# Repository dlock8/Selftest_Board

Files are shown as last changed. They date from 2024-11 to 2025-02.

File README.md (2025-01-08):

# FIRST STATION TEST Selftest Box Assembly 500-1010-021

## Project Overview
This project involves the assembly of a custom **Selftest Circuit Board (PCB)** designed to be part of the **First TestStation** project ([FTS](https://dlock8.github.io/FTS_Website/)).<br>
The primary goal of the selftest board is to provide the necessary electronics and multiple connections to validate the [Interconnect IO Box](https://github.com/dlock8/InterconnectIO_Box).<br>

## Note
Due to minor additions, the Selftest Board Assembly has been updated to become the Selftest Box Assembly. The documentation for these updates has been included in the same repository.

## Documentation

- [Bill of Materials (BOM)](selftest_bd/pdf/BOM_Selftest_Box_510-1010.pdf) – List of components required for assembly.

<br>
<br>

# FIRST STATION TEST Selftest Board Assembly 600-1010-021

This section contains the materials and instructions required to assemble the Selftest Board.

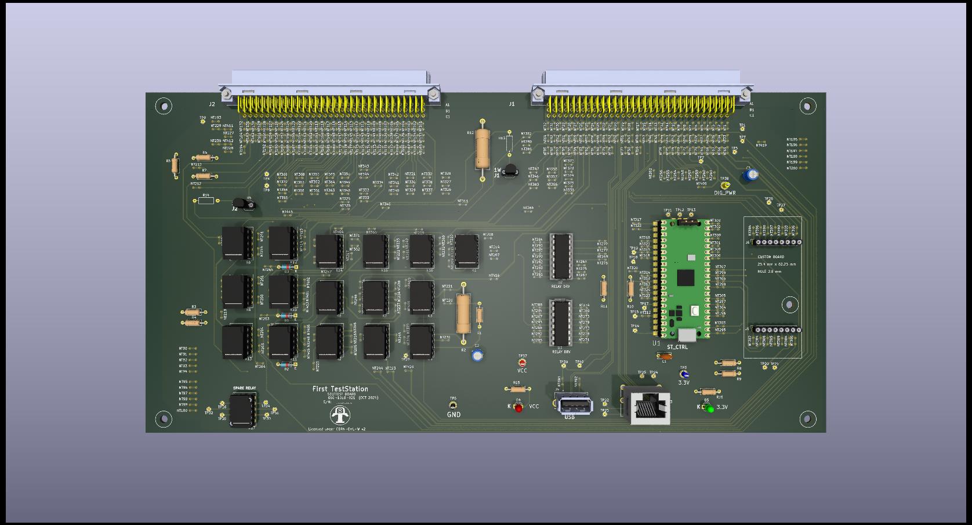
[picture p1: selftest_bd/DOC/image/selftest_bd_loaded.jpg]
Board
 

### Design Tools
- [KiCad 7](https://www.kicad.org/download/) - Free software application used to design the PCB.
- [LibreOffice](https://www.libreoffice.org/download/download-libreoffice/) - Free Software application used to create assembly instructions and the Bill of Materials (BOM).
- [PicPick](https://picpick.app/en/) - Free application to capture and document image.

---
### Features
- **Easy Hand Assembly**: Designed with only through-hole components, making it easy to assemble by hand.
- **Socketed Active Components**: To facilitate easy replacement without unsoldering, most active components are mounted on sockets.
- **Cost-Effective Controller**: The low-cost and powerful **Raspberry Pi Pico Microcontroller** is used to interface with the user and control internal electronics.

## Assembly Instructions
   Follow the document [Assembly_Instructions](selftest_bd/pdf/Selftest_Assembly_Instruction_680-1010.pdf) to complete the assembly of the board.

## Design Files
- [Gerber Files](https://github.com/dlock8/Selftest_Board/tree/main/selftest_bd/gerber_to_order) – Gerber files for PCB fabrication (JLCPCB is the one used by the project).
- [Assembly Schematic](selftest_bd/pdf/Selftest_Assembly_Diagram_670-1010.pdf) – Parts and value to help hand assemblies of components.
- [Electrical Schematic](selftest_bd/pdf/Selftest_Schematic_640-1010.pdf) – Review the full electrical schematic diagram for reference.
- [Bill of Materials (BOM)](selftest_bd/pdf/BOM_Selftest_Board_610-1010.pdf) – List of components required for assembly.

---

## License

This project is licensed under the terms of the [CERN Open Hardware Licence Version 2 - Weakly Reciprocal (CERN-OHL-W 2.0)](https://ohwr.org/cern_ohl_w_v2.txt).

See the [LICENSE](./LICENSE) file in this repository for more details.

---

## History
- **Version 1.0**: The initial version of the PCB (600-1010-010) was assembled and tested. However, the main connectors J1 and J2 were reversed, making the board unusable.
- **Version 2.0**:This version includes corrections to the connector errors. The board was assembled and tested, but errors were found in the wiring of the USB and RJ45 connectors.
- **Version 2.1**: This version addresses all errors identified in Version 2.0. As of now, Version 2.1 has not yet been assembled or tested.
---

## Contact
For any issues or further questions, feel free to contact me at [daniellockhead@gmail.com] or open an issue on GitHub.

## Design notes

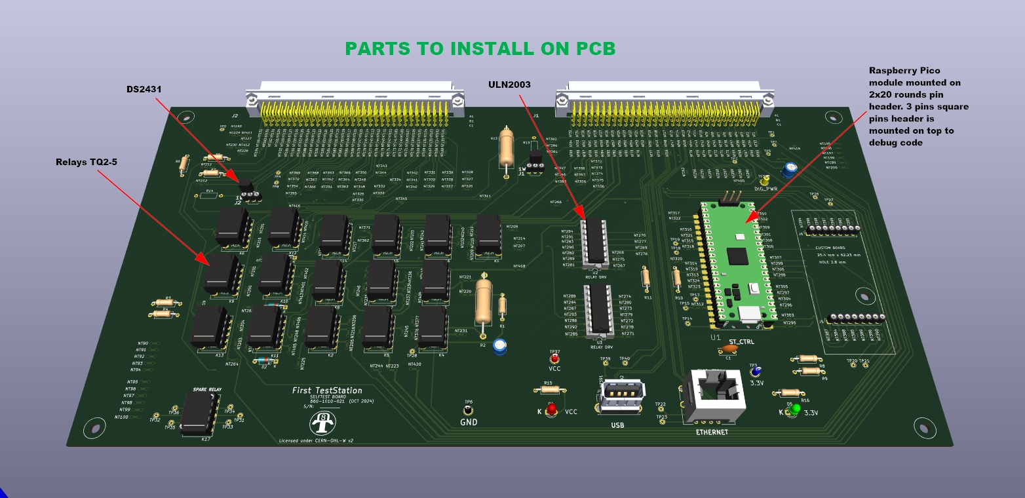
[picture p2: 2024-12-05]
selftest_bd/DOC/image/selftest_bd_loaded2.jpg

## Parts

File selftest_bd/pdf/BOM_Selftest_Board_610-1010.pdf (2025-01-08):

# BOM Selest Board

610-1010-021

Component for this board has been selected to be not expensive and available over the world. The quanty specified on the BOM are the required quanty and not the quanty received because most of the components sales by AliExpress are coming in a lot of 5 or more.

ITEM | Ref | Qty | Value | Component number | Component Link | Footprint
1 | C1, | 1 | 0.1uF | 104(0.1uF) | hps://www.aliexpress.com/item/1005002290441861.html?spm=a2g0o.cart.0.0.47a938dapeqfLF&mp=1 | Capacitor_THT:C_Disc_D6.0mm_W2.5mm_P5.00mm
2 | C2, C3, | 2 | 10uF | Need 10uF only | hps://www.aliexpress.com/item/1005001831366715.html?spm=a2g0o.order_list.order_list_main.128.18751802TGrCM3 | Capacitor_THT:CP_Radial_D4.0mm_P1.50mm
3 | D1, D2, D3, | 3 | 1N4148 | D0-35 | hps://www.aliexpress.com/item/1005002761024460.html?spm=a2g0o.order_list.order_list_main.134.18751802TGrCM3 | Diode_THT:D_DO-35_SOD27_P7.62mm_Horizontal
4 | D4, D5 | 2 | Red,Green Led 3m 5 color mixing | | hps://www.aliexpress.com/item/32890682652.html?spm=a2g0o.cart.0.0.484b38da3R3jzV&mp=1 | LED_THT:LED_D3.0mm
5 | J1, J2, | 2 | 9001-14961C00A | 396-RA-F | hps://www.aliexpress.com/item/32808173331.html?spm=a2g0o.order_detail.order_detail_item.3.8a9af19cRF49dn | 9001-11961:900114961C00A
6 | J3, | 1 | RJ45 | NO LED 180 Degress | hps://www.aliexpress.com/item/4001249545815.html?spm=a2g0o.order_list.order_list_main.5.21ef18023qhtdr | RJ45:CUI_CRJ028-1H-TH
7 | J4, | 1 | USB-VERTICAL | USB-A1VSB6 | hps://www.aliexpress.com/item/1005003366091753.html?spm=a2g0o.order_detail.order_detail_item.3.16c6f19cv420cM | USB-A:ONSHORE_USB-A1VSB6
8 | J5, J6, | 2 | 8 x 2.54mm | Cut to length | hps://www.aliexpress.com/item/1005005053790061.html?spm=a2g0o.order_list.order_list_main.16.2c1a1802vA8wf5 | Connector_PinSocket_2.54mm:PinSocket_1x08_P2.54mm_Vercal
9 | K1,K2,K3,K4,K5,K6,K7,K8,K9,K10,K11, K12,K13,K14,K15,K16,K17 | 17 | TQ2-5 | TQ2-5V | hps://www.aliexpress.com/item/1005004349797638.html?spm=a2g0o.order_detail.order_detail_item.3.29bdf19cH6EBpl | Relay_THT:Relay_DPDT_FRT5
10 | R1, | 1 | 100 | 1% 1/4W Resistor Kit | hps://www.aliexpress.com/item/1005001818485416.html?spm=a2g0o.cart.0.0.405a38daqyYISw&mp=1 | Resistor_THT:R_Axial_DIN0207_L6.3mm_D2.5mm_P10.16mm_Horizontal
11 | R2,R12, | 2 | 10 | 10R 3W | hps://www.aliexpress.com/item/1005005249422833.html?spm=a2g0o.cart.0.0.6c0b38dax2jDId&mp=1 | Resistor_THT:R_Axial_DIN0617_L17.0mm_D6.0mm_P25.40mm_Horizontal
12 | R3, R4, R10,R11 | 2 | 10K | 1% 1/4W Resistor Kit | hps://www.aliexpress.com/item/1005001818485416.html?spm=a2g0o.cart.0.0.405a38daqyYISw&mp=1 | Resistor_THT:R_Axial_DIN0309_L9.0mm_D3.2mm_P12.70mm_Horizontal
13 | R6, | 1 | 10 | 1% 1/4W Resistor Kit | hps://www.aliexpress.com/item/1005001818485416.html?spm=a2g0o.cart.0.0.405a38daqyYISw&mp=1 | Resistor_THT:R_Axial_DIN0207_L6.3mm_D2.5mm_P10.16mm_Horizontal
14 | R5,R7 | 2 | 4.7 | 1% 1/4W Low value Resistor Kit | hps://www.aliexpress.com/item/4000174550644.html?spm=a2g0o.order_list.order_list_main.47.641f1802HxQ52S | Resistor_THT:R_Axial_DIN0207_L6.3mm_D2.5mm_P10.16mm_Horizontal
15 | R8, R9, R13, R14 | 2 | 4.7K | 1% 1/4W Resistor Kit | hps://www.aliexpress.com/item/1005001818485416.html?spm=a2g0o.cart.0.0.405a38daqyYISw&mp=1 | Resistor_THT:R_Axial_DIN0207_L6.3mm_D2.5mm_P10.16mm_Horizontal
16 | R13, R14 | 2 | Not Installed | 1% 1/4W Resistor Kit | hps://www.aliexpress.com/item/1005001818485416.html?spm=a2g0o.cart.0.0.405a38daqyYISw&mp=1 | Resistor_THT:R_Axial_DIN0207_L6.3mm_D2.5mm_P10.16mm_Horizontal
17 | R15, | 1 | 470 | 1% 1/4W Resistor Kit | hps://www.aliexpress.com/item/1005001818485416.html?spm=a2g0o.cart.0.0.405a38daqyYISw&mp=1 | Resistor_THT:R_Axial_DIN0207_L6.3mm_D2.5mm_P10.16mm_Horizontal
18 | R16, | 1 | 330 | 1% 1/4W Resistor Kit | hps://www.aliexpress.com/item/1005001818485416.html?spm=a2g0o.cart.0.0.405a38daqyYISw&mp=1 | Resistor_THT:R_Axial_DIN0207_L6.3mm_D2.5mm_P10.16mm_Horizontal
19 | U1, | 1 | Rasberry Pico | SC0915 | hps://www.digikey.ca/en/products/detail/raspberry-pi/SC0915/13624793?s=N4IgTCBcDaIMoGEAMBOAjAVhAXQL5A | MCU_RaspberryPi_and_Boards:RPi_Pico_SMD_TH
20 | U1_male_pin | 1 | 20 x 2.54mm | 1x40P male L-11.96mm | hps://www.aliexpress.com/item/1005005053790061.html?spm=a2g0o.order_list.order_list_main.16.2c1a1802vA8wf5 | oponnal
21 | U1_socket | 1 | 20 x 2.54mm | 1x40P Female Gold | hps://www.aliexpress.com/item/1005005053790061.html?spm=a2g0o.order_list.order_list_main.16.2c1a1802vA8wf5 | oponnal
22 | U2, U3, | 2 | ULN2003A | ULN2003AN DIP | hps://www.aliexpress.com/item/1005003321113000.html?spm=a2g0o.order_list.order_list_main.55.68501802kRK9e9 | Package_DIP:DIP-16_W7.62mm_LongPads
23 | U2_socket, U3_socket, | 2 | 16 pin socket | round hole DIP-16p | hps://www.aliexpress.com/item/4000578067926.html?spm=a2g0o.cart.0.0.2bcc38da88bsXx&mp=1 | Package_DIP:DIP-16_W7.62mm_LongPads
24 | U4, U5 | 2 | DS2431 | Memory | hps://www.aliexpress.com/item/1005003797567885.html?spm=a2g0o.cart.0.0.784438daDIqgr6&mp=1 | Package_TO_SOT_THT:TO-92_Inline
25 | U4_socket, U5_socket | 2 | 3 x 2.54mm | 1x40P Female Gold | hps://www.aliexpress.com/item/1005005053790061.html?spm=a2g0o.order_list.order_list_main.16.2c1a1802vA8wf5 | oponnal
26 | TP6.TP3,TP37,TP38 | 4 | Testpoint | Black,Blue,Red,Yellow | hps://www.aliexpress.com/item/1005001843784820.html?spm=a2g0o.cart.0.0.7faa38daxJjUNz&mp=1 | TestPoint_Loop_D2.54mm_Drill1.5mm_Beaded
27 | PCB Selest Board | 1 | 660-1010-021 | | hps://jlcpcb.com/

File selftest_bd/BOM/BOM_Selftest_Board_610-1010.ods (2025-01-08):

BOM Selftest Board
610-1010-021
Component for this board has been selected to be not expensive and available over the world. The quantity specified on the BOM are the required quantity and not the quantity received because most of the components sales by AliExpress are coming in a lot of 5 or more.
ITEM | Ref | Qty | Value | Component number | Component Link | Footprint
1 | C1, | 1 | 0.1uF | 104(0.1uF) | https://www.aliexpress.com/item/1005002290441861.html?spm=a2g0o.cart.0.0.47a938dapeqfLF&mp=1 | Capacitor_THT:C_Disc_D6.0mm_W2.5mm_P5.00mm
2 | C2, C3, | 2 | 10uF | Need 10uF only | https://www.aliexpress.com/item/1005001831366715.html | Capacitor_THT:CP_Radial_D4.0mm_P1.50mm
3 | D1, D2, D3, | 3 | 1N4148 | D0-35 | https://www.aliexpress.com/item/1005002761024460.html | Diode_THT:D_DO-35_SOD27_P7.62mm_Horizontal
4 | D4, D5 | 2 | Red,Green Led 3mm | 5 color mixing | https://www.aliexpress.com/item/32890682652.html?spm=a2g0o.cart.0.0.484b38da3R3jzV&mp=1 | LED_THT:LED_D3.0mm
5 | J1, J2, | 2 | 9001-14961C00A | 396-RA-F | https://www.aliexpress.com/item/32808173331.html | 9001-11961:900114961C00A
6 | J3, | 1 | RJ45 | NO LED 180 Degress | https://www.aliexpress.com/item/4001249545815.html | RJ45:CUI_CRJ028-1H-TH
7 | J4, | 1 | USB-VERTICAL | USB-A1VSB6 | https://www.aliexpress.com/item/1005003366091753.html | USB-A:ONSHORE_USB-A1VSB6
8 | J5, J6, | 2 | 8 x 2.54mm | Cut to length | https://www.aliexpress.com/item/1005005053790061.html | Connector_PinSocket_2.54mm:PinSocket_1x08_P2.54mm_Vertical
9 | K1,K2,K3,K4,K5,K6,K7,K8,K9,K10,K11, K12,K13,K14,K15,K16,K17 | 17 | TQ2-5 | TQ2-5V | https://www.aliexpress.com/item/1005004349797638.html | Relay_THT:Relay_DPDT_FRT5
10 | R1, | 1 | 100 | 1% 1/4W Resistor Kit | https://www.aliexpress.com/item/1005001818485416.html?spm=a2g0o.cart.0.0.405a38daqyYISw&mp=1 | Resistor_THT:R_Axial_DIN0207_L6.3mm_D2.5mm_P10.16mm_Horizontal
11 | R2,R12, | 2 | 10 | 10R 3W | https://www.aliexpress.com/item/1005005249422833.html?spm=a2g0o.cart.0.0.6c0b38dax2jDId&mp=1 | Resistor_THT:R_Axial_DIN0617_L17.0mm_D6.0mm_P25.40mm_Horizontal
12 | R3, R4, R10,R11 | 2 | 10K | 1% 1/4W Resistor Kit | https://www.aliexpress.com/item/1005001818485416.html?spm=a2g0o.cart.0.0.405a38daqyYISw&mp=1 | Resistor_THT:R_Axial_DIN0309_L9.0mm_D3.2mm_P12.70mm_Horizontal
13 | R6, | 1 | 10 | 1% 1/4W Resistor Kit | https://www.aliexpress.com/item/1005001818485416.html?spm=a2g0o.cart.0.0.405a38daqyYISw&mp=1 | Resistor_THT:R_Axial_DIN0207_L6.3mm_D2.5mm_P10.16mm_Horizontal
14 | R5,R7 | 2 | 4.7 | 1% 1/4W Low value Resistor Kit | https://www.aliexpress.com/item/4000174550644.html | Resistor_THT:R_Axial_DIN0207_L6.3mm_D2.5mm_P10.16mm_Horizontal
15 | R8, R9, R13, R14 | 2 | 4.7K | 1% 1/4W Resistor Kit | https://www.aliexpress.com/item/1005001818485416.html?spm=a2g0o.cart.0.0.405a38daqyYISw&mp=1 | Resistor_THT:R_Axial_DIN0207_L6.3mm_D2.5mm_P10.16mm_Horizontal
16 | R13, R14 | 2 | Not Installed | 1% 1/4W Resistor Kit | https://www.aliexpress.com/item/1005001818485416.html?spm=a2g0o.cart.0.0.405a38daqyYISw&mp=1 | Resistor_THT:R_Axial_DIN0207_L6.3mm_D2.5mm_P10.16mm_Horizontal
17 | R15, | 1 | 470 | 1% 1/4W Resistor Kit | https://www.aliexpress.com/item/1005001818485416.html?spm=a2g0o.cart.0.0.405a38daqyYISw&mp=1 | Resistor_THT:R_Axial_DIN0207_L6.3mm_D2.5mm_P10.16mm_Horizontal
18 | R16, | 1 | 330 | 1% 1/4W Resistor Kit | https://www.aliexpress.com/item/1005001818485416.html?spm=a2g0o.cart.0.0.405a38daqyYISw&mp=1 | Resistor_THT:R_Axial_DIN0207_L6.3mm_D2.5mm_P10.16mm_Horizontal
19 | U1, | 1 | Rasberry Pico | SC0915 | https://www.digikey.ca/en/products/detail/raspberry-pi/SC0915/13624793?s=N4IgTCBcDaIMoGEAMBOAjAVhAXQL5A | MCU_RaspberryPi_and_Boards:RPi_Pico_SMD_TH
20 | U1_male_pin | 1 | 20 x 2.54mm | 1x40P male L-11.96mm | https://www.aliexpress.com/item/1005005053790061.html | optionnal
21 | U1_socket | 1 | 20 x 2.54mm | 1x40P Female Gold | https://www.aliexpress.com/item/1005005053790061.html | optionnal
22 | U2, U3, | 2 | ULN2003A | ULN2003AN DIP | https://www.aliexpress.com/item/1005003321113000.html | Package_DIP:DIP-16_W7.62mm_LongPads
23 | U2_socket, U3_socket, | 2 | 16 pin socket | round hole DIP-16p | https://www.aliexpress.com/item/4000578067926.html?spm=a2g0o.cart.0.0.2bcc38da88bsXx&mp=1 | Package_DIP:DIP-16_W7.62mm_LongPads
24 | U4, U5 | 2 | DS2431 | Memory | https://www.aliexpress.com/item/1005003797567885.html?spm=a2g0o.cart.0.0.784438daDIqgr6&mp=1 | Package_TO_SOT_THT:TO-92_Inline
25 | U4_socket, U5_socket | 2 | 3 x 2.54mm | 1x40P Female Gold | https://www.aliexpress.com/item/1005005053790061.html | optionnal
26 | TP6.TP3,TP37,TP38 | 4 | Testpoint | Black,Blue,Red,Yellow | https://www.aliexpress.com/item/1005001843784820.html?spm=a2g0o.cart.0.0.7faa38daxJjUNz&mp=1 | TestPoint_Loop_D2.54mm_Drill1.5mm_Beaded
27 | PCB Selftest Board | 1 | 660-1010-021 |  | https://jlcpcb.com/

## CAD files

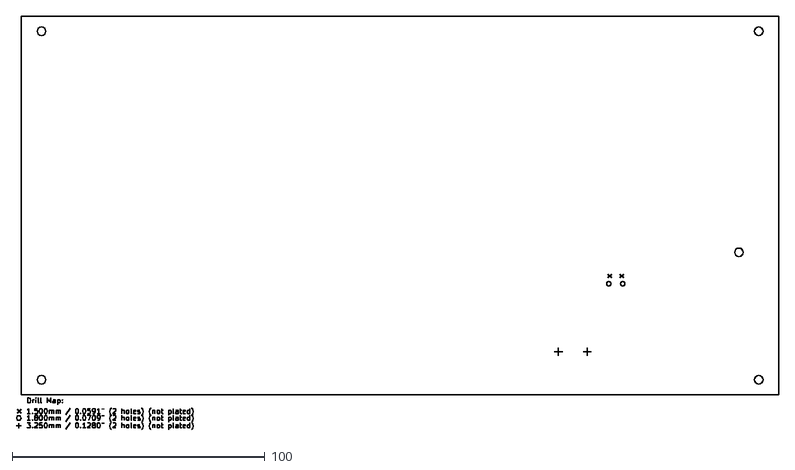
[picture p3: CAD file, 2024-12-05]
selftest_bd/Selftest-gerbers/selftest_bd-NPTH-drl_map.dxf
302.1 x 163.9

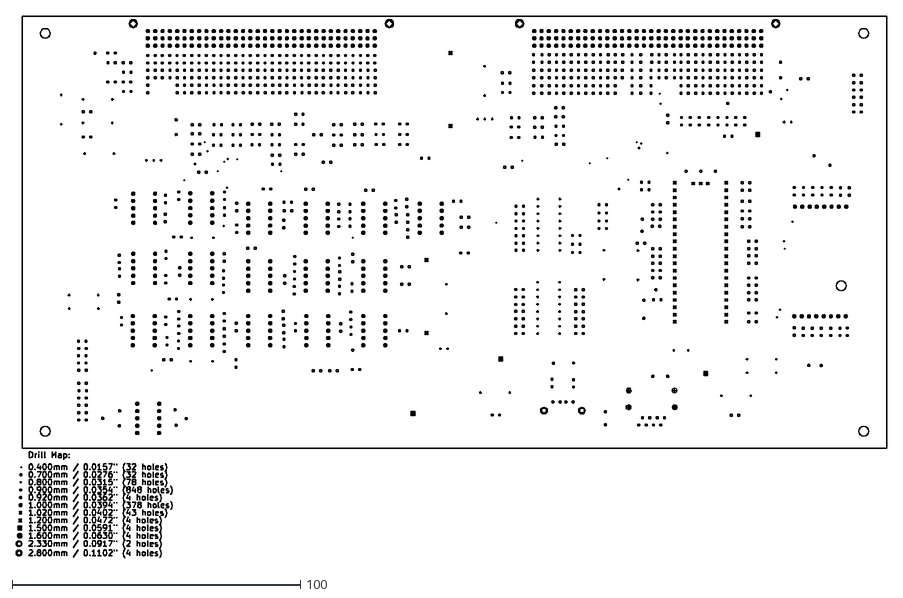
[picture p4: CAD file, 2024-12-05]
selftest_bd/Selftest-gerbers/selftest_bd-PTH-drl_map.dxf
302.1 x 188.0

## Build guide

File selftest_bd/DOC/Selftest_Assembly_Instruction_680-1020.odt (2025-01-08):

SELFTEST BOARD ASSEMBLY INSTRUCTIONS

680-1020-010

This document provides detailed instructions on how to build the Selftest board.

The board has been designed to be assembled by hand or by automatic machine if larger quantities are required. In this document, the instructions are for the hand assembly method.

In the hand assembly method, component sockets will be used for most parts to facilitate component replacement and make repairs easier.

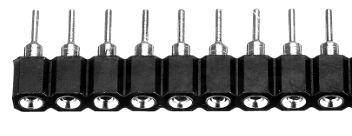
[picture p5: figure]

The round hole header type is preferred due to its smaller size, lower contact resistance and versatility. It can be used directly to mount through-hole electronic components, such as relays and integrated circuits. A round hole male header is required to match with the round hole female header when components do not have pins pre-installed. In the case of the Selftest board, the Raspberry Pi Pico controller will be mounted using a round hole male header.

### Assembly Strategy

To facilitate hand soldering of components, the suggested strategy is to solder all the round circular sockets first. Achieving straight alignment of the round sockets can be tricky and requires some practical experience.

Once the round sockets are soldered, the other components can be installed, following the rule of soldering smaller components first, then moving on to larger ones.

### ASSEMBLY INSTRUCTIONS

Follow these steps to successfully assemble the PCB:

#### Preparation

- Ensure you have the required components and tools (e.g., soldering iron, flux, multimeter).
- Review the Bill of Materials (BOM) to ensure all parts are available.
- Refer to the document Selftest_assembly.pdf to identify the component values to be installed.
- Do not mount components marked N.A. (Not Assembled).

The picture below of the Selftest Board shows all parts to be soldered.

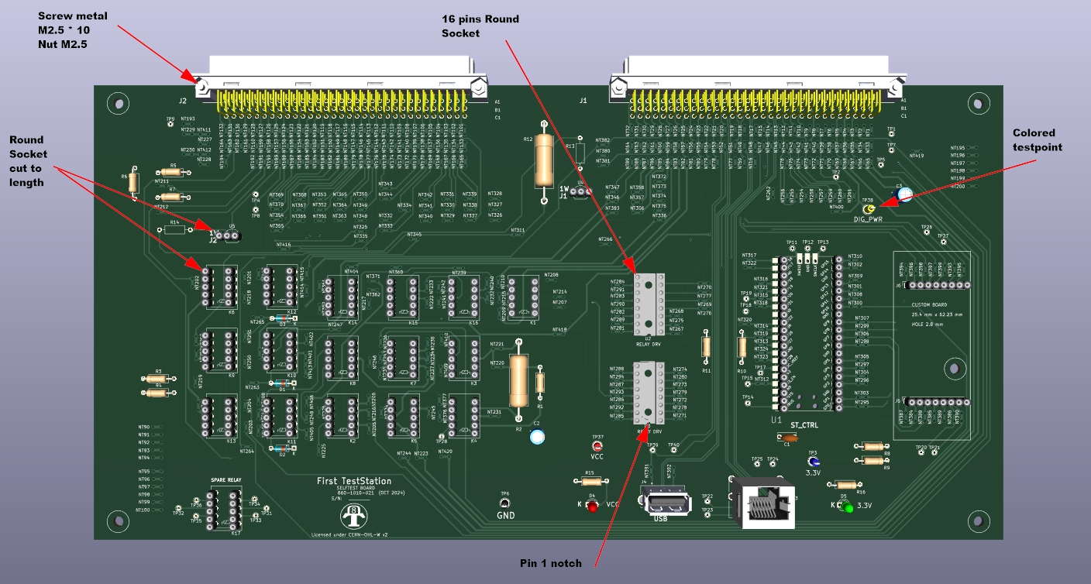
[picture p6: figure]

### Step-by-Step Soldering Instructions

1. Solder Round Pin Sockets: Begin by soldering the round pin sockets (cut to length) for components such as the Microcontroller, ICs, and relays.
2. Solder 16-Pin Sockets: Solder the 16-pin sockets to mount integrated circuits. If 16-pin round sockets are unavailable, round socket headers can be used as an alternative.
3. Install Large Connectors: Place large connectors J1 and J2 on the PCB. Install the retaining screws before soldering to ensure they are securely mounted.
4. Install Smaller Components: Start by soldering the smaller components, such as resistors, capacitors, Leds, transistors and test points, before moving on to larger components.
5. Solder Other Connectors: Attach and solder all remaining connectors.
6. Solder Pins Header on Pico: Solder 2 x 20 round pin headers on the bottom of the Pico module. If software code modifications are necessary, solder a 3-pin round socket on the top of the module for debugging. A 3-pin round header will be mounted on top of the 3-pin socket to function as a sacrificial connector.

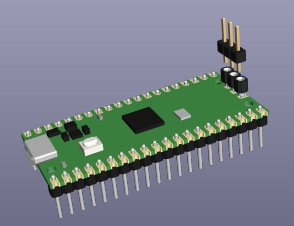
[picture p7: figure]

A this point, the soldering is complete and only parts on socket need to be installed.

### Step-by-Step Mounting Parts Instructions


1. Mount Relays: Start by installing all the relays. Ensure that each relay is installed with the correct polarity (refer to the picture for guidance).
2. Mount Integrated Circuits: Next, install the integrated circuits. Make sure to align pin 1 of each integrated circuit with the pin 1 marking on the board.
3. Mount Pico Module: Program one Raspberry Pi Pico with the Selftest software. Follow the instructions from Selftest_code GitHub Repository (https://github.com/dlock8/Selftest_code). Once programmed, install the Pico on the Board at the location marked "ST_CTRL." Ensure the module is installed in the correct orientation.

At this point, the board assembly is complete, and initial testing can be performed.

### TESTING

1. Shorts Verification: Using a multimeter, verify that there are no shorts present between all the test points: VCC, GND,3V3, and DIG_PWR. If any shorts are detected, make the necessary corrections before applying power to the board.
2. First Power On: The Selftest board does not have its own power input and requires power from an external board. However, the power can be supplied through the Raspberry Pi Pico's USB connector.
  - Connect a USB cable between your computer and the Pico board.
    - The red LED (D4) should turn ON, indicating VCC power.
    - The green LED (D5) should turn ON, indicating 3.3V power.
    - The LED on the Pico module should slowly flash, indicating the Pico heartbeat.
  - Using a multimeter, verify the following:
    - 5V between the VCC and GND test points.
    - 3.3V between the 3V3 and GND test points.

Initial testing is complete. Comprehensive testing of the board will require additional hardware and will be included in the First Test Station documentation.

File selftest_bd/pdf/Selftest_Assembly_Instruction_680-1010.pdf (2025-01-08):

SELFTEST BOARD ASSEMBLY INSTRUCTIONS 680-1020-010

This document provides detailed instructions on how to build the Selftest board.
The board has been designed to be assembled by hand or by automatic machine if larger quantities are required. In this document, the instructions are for the hand assembly method.
In the hand assembly method, component sockets will be used for most parts to facilitate component replacement and make repairs easier.

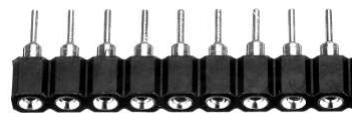
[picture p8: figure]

The round hole header type is preferred due to its smaller size, lower contact resistance and versatility. It can be used directly to mount through-hole electronic components, such as relays and integrated circuits. A round hole male header is required to match with the round hole female header when components do not have pins pre-installed. In the case of the Selftest board, the Raspberry Pi Pico controller will be mounted using a round hole male header.

Assembly Strategy
To facilitate hand soldering of components, the suggested strategy is to solder all the round circular sockets first. Achieving straight alignment of the round sockets can be tricky and requires some practical experience.
Once the round sockets are soldered, the other components can be installed, following the rule of soldering smaller components first, then moving on to larger ones.

ASSEMBLY INSTRUCTIONS
Follow these steps to successfully assemble the PCB:

Preparation
- Ensure you have the required components and tools (e.g., soldering iron, flux, multimeter).
- Review the Bill of Materials (BOM) to ensure all parts are available.
- Refer to the document Selftest_assembly.pdf to identify the component values to be installed.
- Do not mount components marked N.A. (Not Assembled).

The picture below of the Selftest Board shows all parts to be soldered.

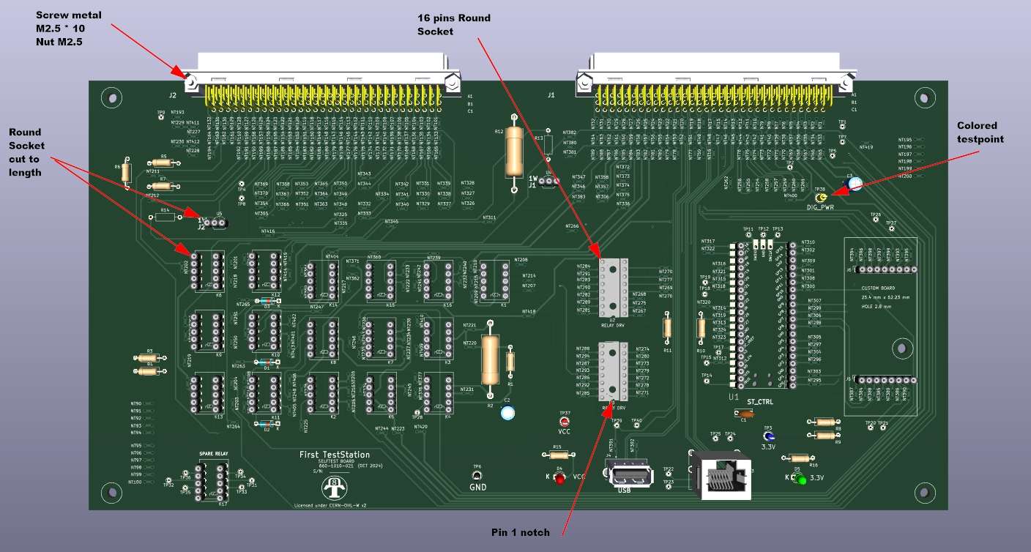
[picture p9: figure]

Step-by-Step Soldering Instructions

### 1. Solder Round Pin Sockets: Begin by soldering the round pin sockets (cut to length) for

components such as the Microcontroller, ICs, and relays.
2. Solder 16-Pin Sockets: Solder the 16-pin sockets to mount integrated circuits. If 16-pin round sockets are unavailable, round socket headers can be used as an alternative.
3. Install Large Connectors: Place large connectors J1 and J2 on the PCB. Install the retaining screws before soldering to ensure they are securely mounted.
4. Install Smaller Components: Start by soldering the smaller components, such as resistors, capacitors, Leds, transistors and test points, before moving on to larger components.
5. Solder Other Connectors: Attach and solder all remaining connectors.

### 6. Solder Pins Header on Pico: Solder 2 x 20 round pin headers on the bottom of the Pico

module. If software code modifications are necessary, solder a 3-pin round socket on the top of the module for debugging. A 3-pin round header will be mounted on top of the 3-pin socket to function as a sacrificial connector.

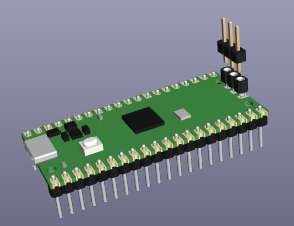
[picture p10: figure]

A this point, the soldering is complete and only parts on socket need to be installed.

Step-by-Step Mounting Parts Instructions

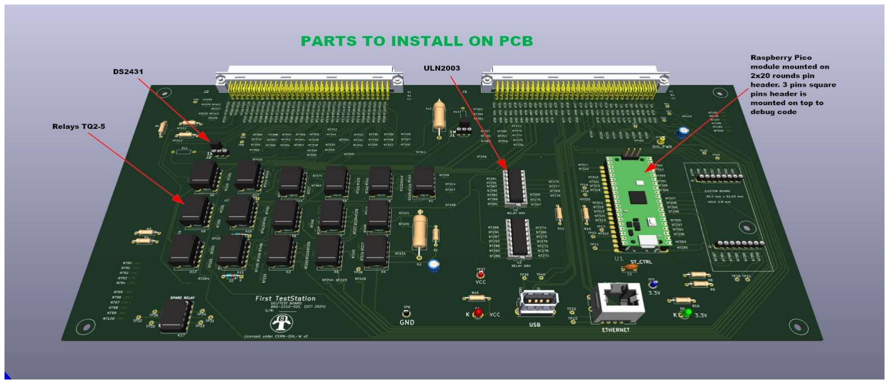
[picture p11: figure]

1. Mount Relays: Start by installing all the relays. Ensure that each relay is installed with the correct polarity (refer to the picture for guidance).
2. Mount Integrated Circuits: Next, install the integrated circuits. Make sure to align pin 1 of each integrated circuit with the pin 1 marking on the board.
3. Mount Pico Module: Program one Raspberry Pi Pico with the Selftest software. Follow the instructions from Selftest_code GitHub Repository. Once programmed, install the Pico on the Board at the location marked "ST_CTRL." Ensure the module is installed in the correct orientation.

At this point, the board assembly is complete, and initial testing can be performed.

TESTING
1. Shorts Verification: Using a multimeter, verify that there are no shorts present between all the test points: VCC, GND,3V3, and DIG_PWR. If any shorts are detected, make the necessary corrections before applying power to the board.
2. First Power On: The Selftest board does not have its own power input and requires power from an external board. However, the power can be supplied through the Raspberry Pi Pico's USB connector.
- Connect a USB cable between your computer and the Pico board.
- The red LED (D4) should turn ON, indicating VCC power.
- The green LED (D5) should turn ON, indicating 3.3V power.
- The LED on the Pico module should slowly flash, indicating the Pico heartbeat.
- Using a multimeter, verify the following:
- 5V between the VCC and GND test points.
- 3.3V between the 3V3 and GND test points.
Initial testing is complete. Comprehensive testing of the board will require additional hardware and will be included in the First Test Station documentation.

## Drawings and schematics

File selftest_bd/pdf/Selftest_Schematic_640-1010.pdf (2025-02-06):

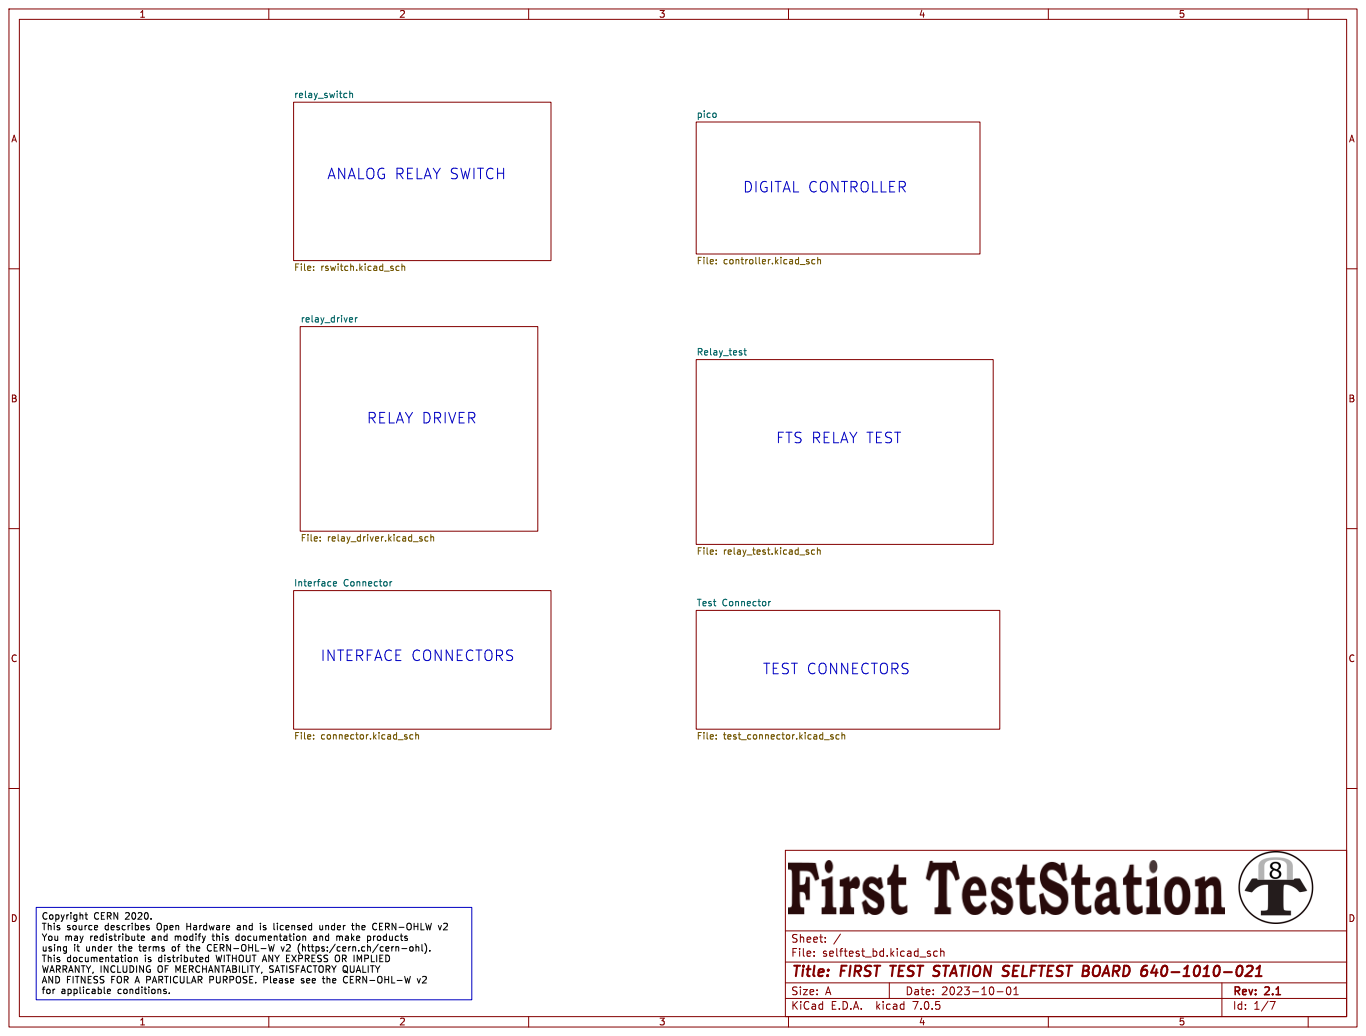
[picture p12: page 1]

pico File: controller.kicad_sch Test Connector File: test_connector.kicad_sch Relay_test File: relay_test.kicad_sch

File: selftest_bd.kicad_sch Sheet: /
Id: 1/7 Title: FIRST TEST STATION SELFTEST BOARD 640-1010-021

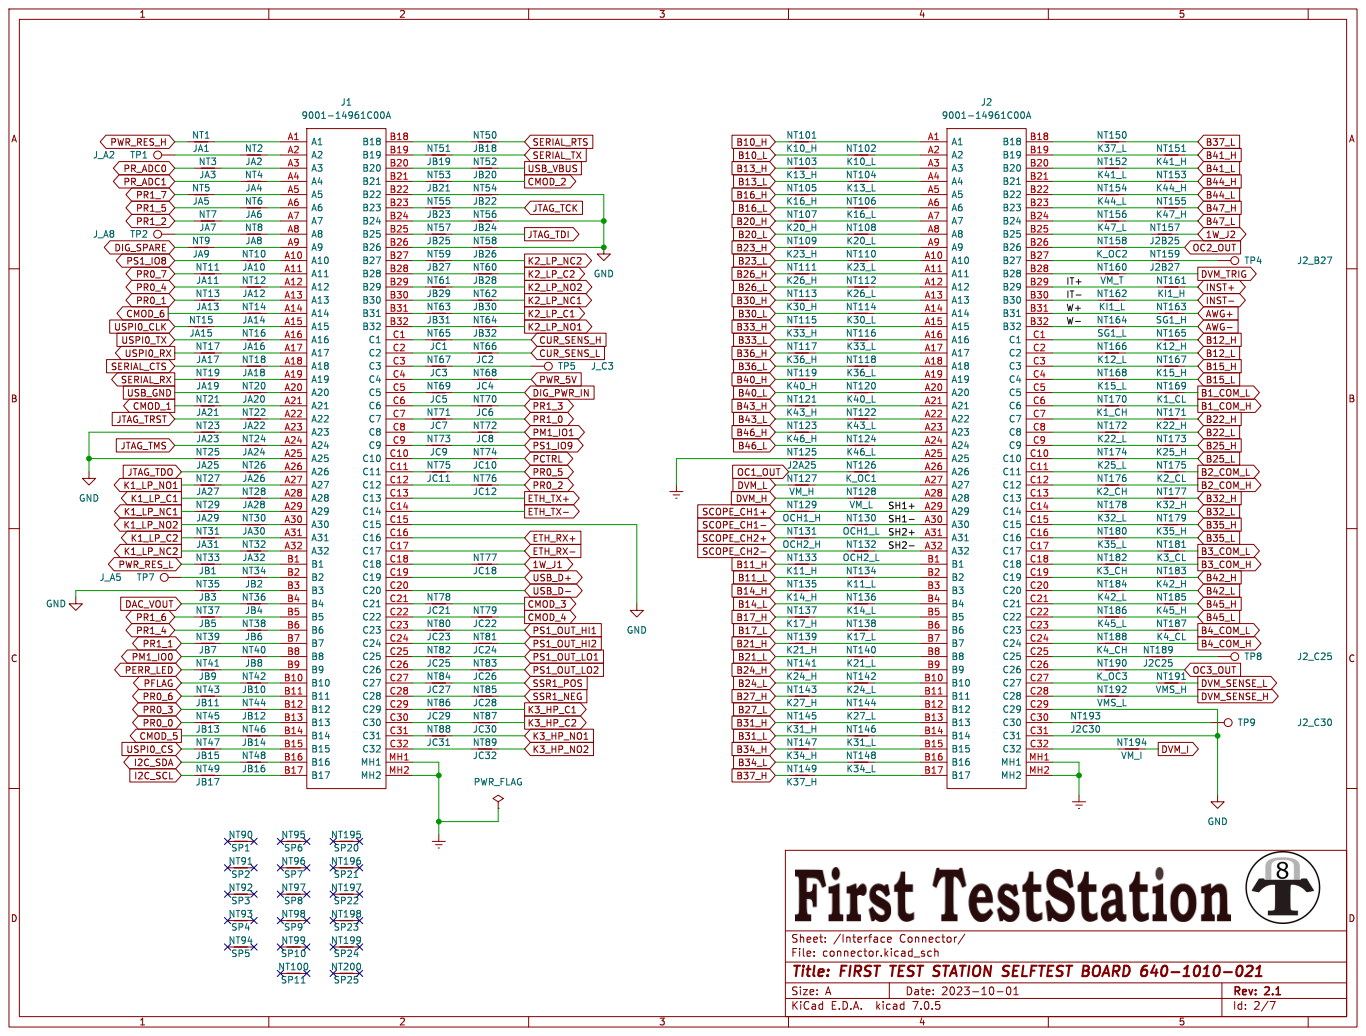
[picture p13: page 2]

Id: 2/7 Title: FIRST TEST STATION SELFTEST BOARD 640-1010-021

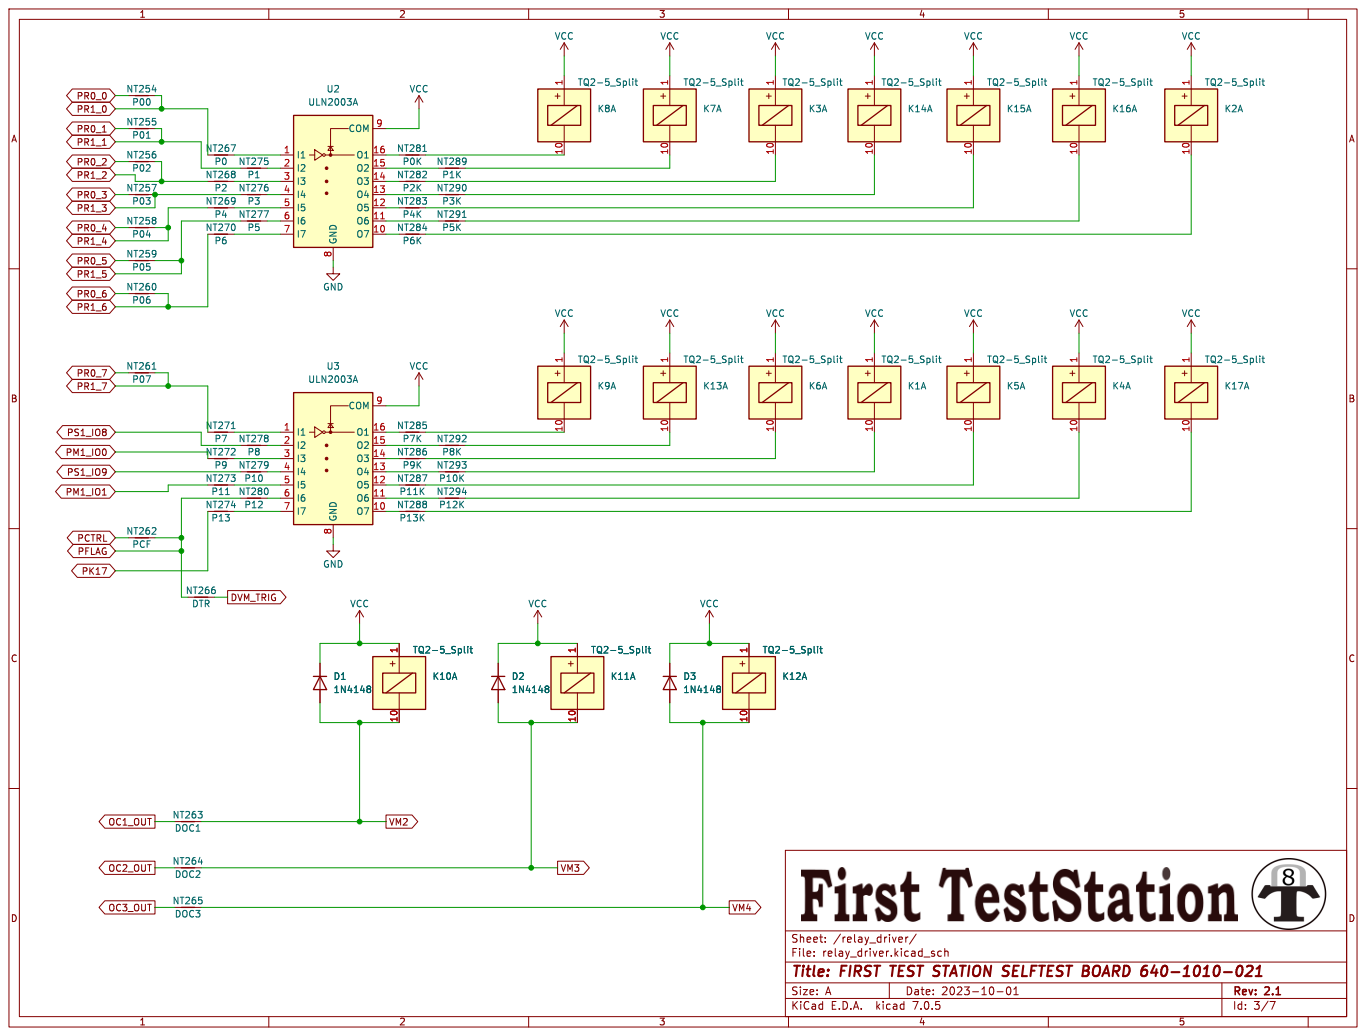
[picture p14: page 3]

File: relay_driver.kicad_sch Sheet: /relay_driver/
Id: 3/7 Title: FIRST TEST STATION SELFTEST BOARD 640-1010-021

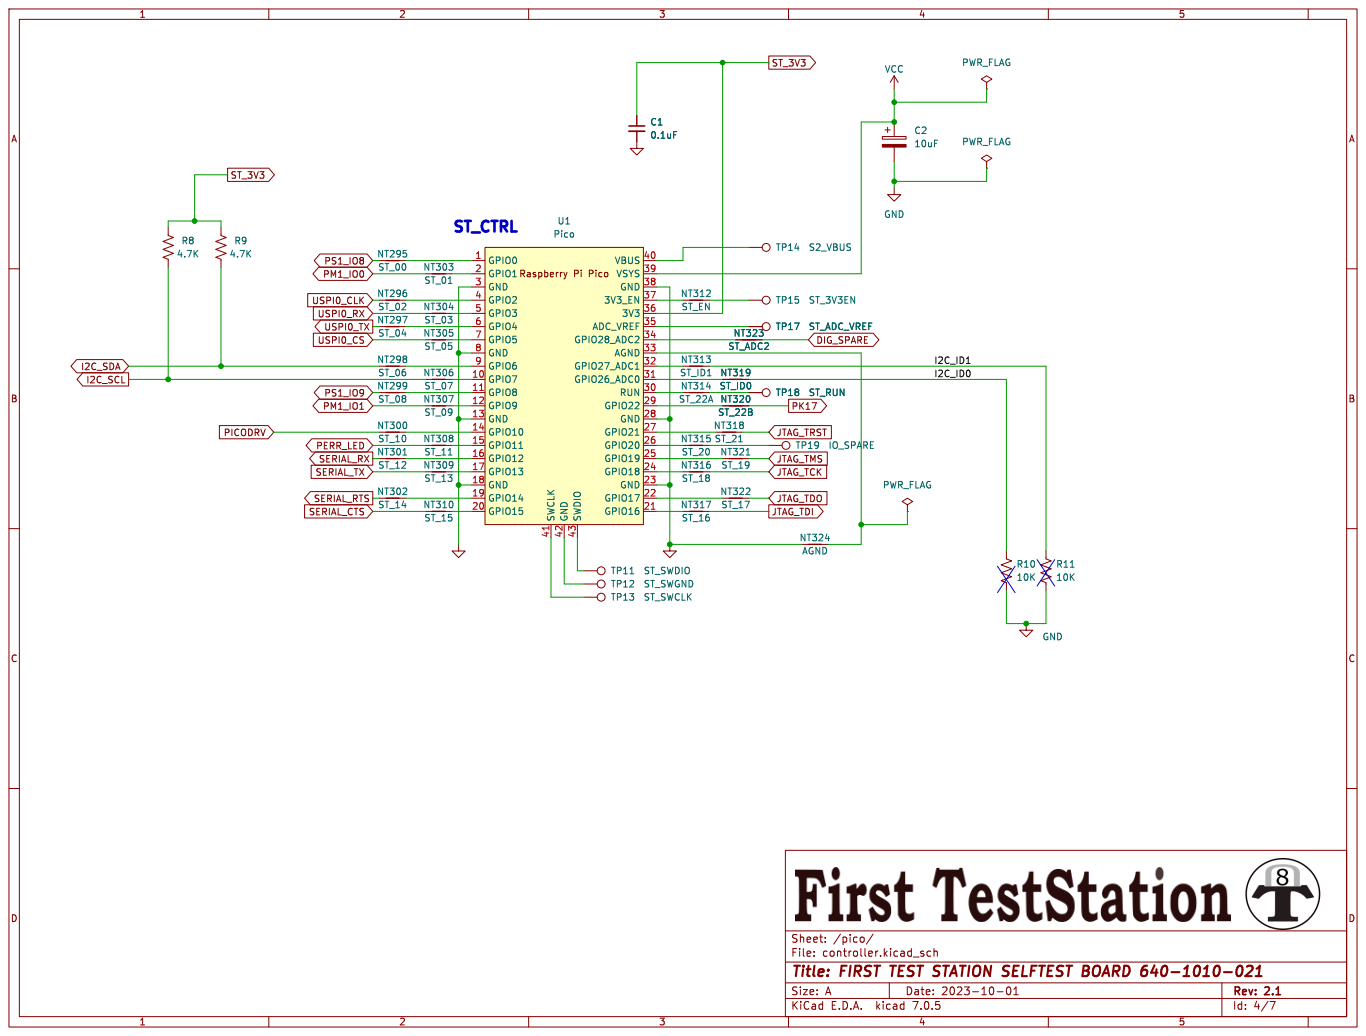
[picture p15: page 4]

File: controller.kicad_sch Sheet: /pico/
Id: 4/7 Title: FIRST TEST STATION SELFTEST BOARD 640-1010-021

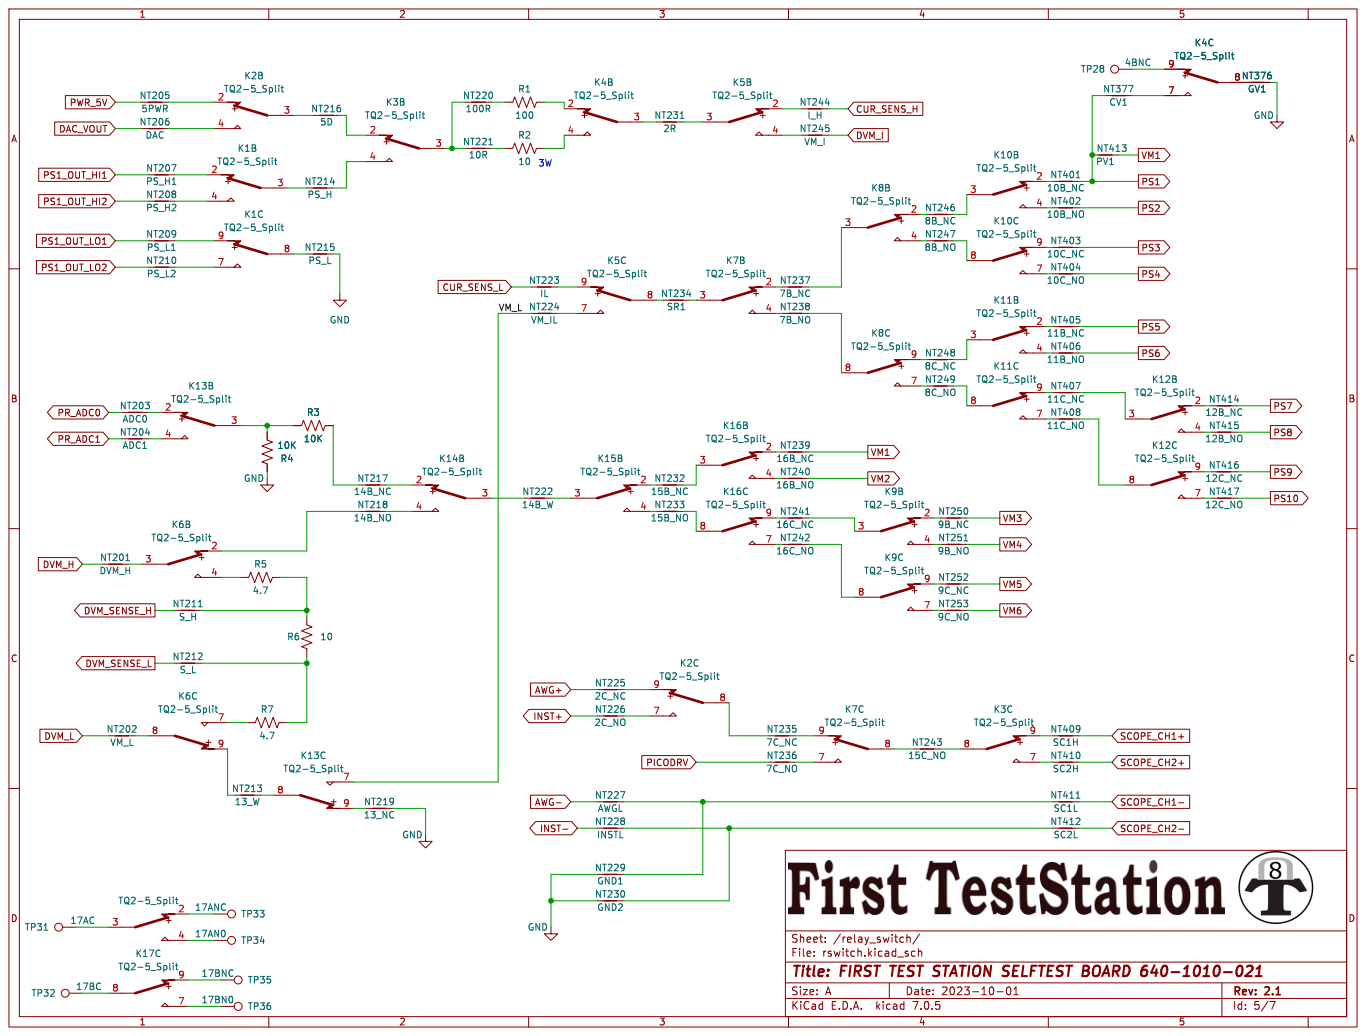
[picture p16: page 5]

File: rswitch.kicad_sch Sheet: /relay_switch/
Id: 5/7 Title: FIRST TEST STATION SELFTEST BOARD 640-1010-021

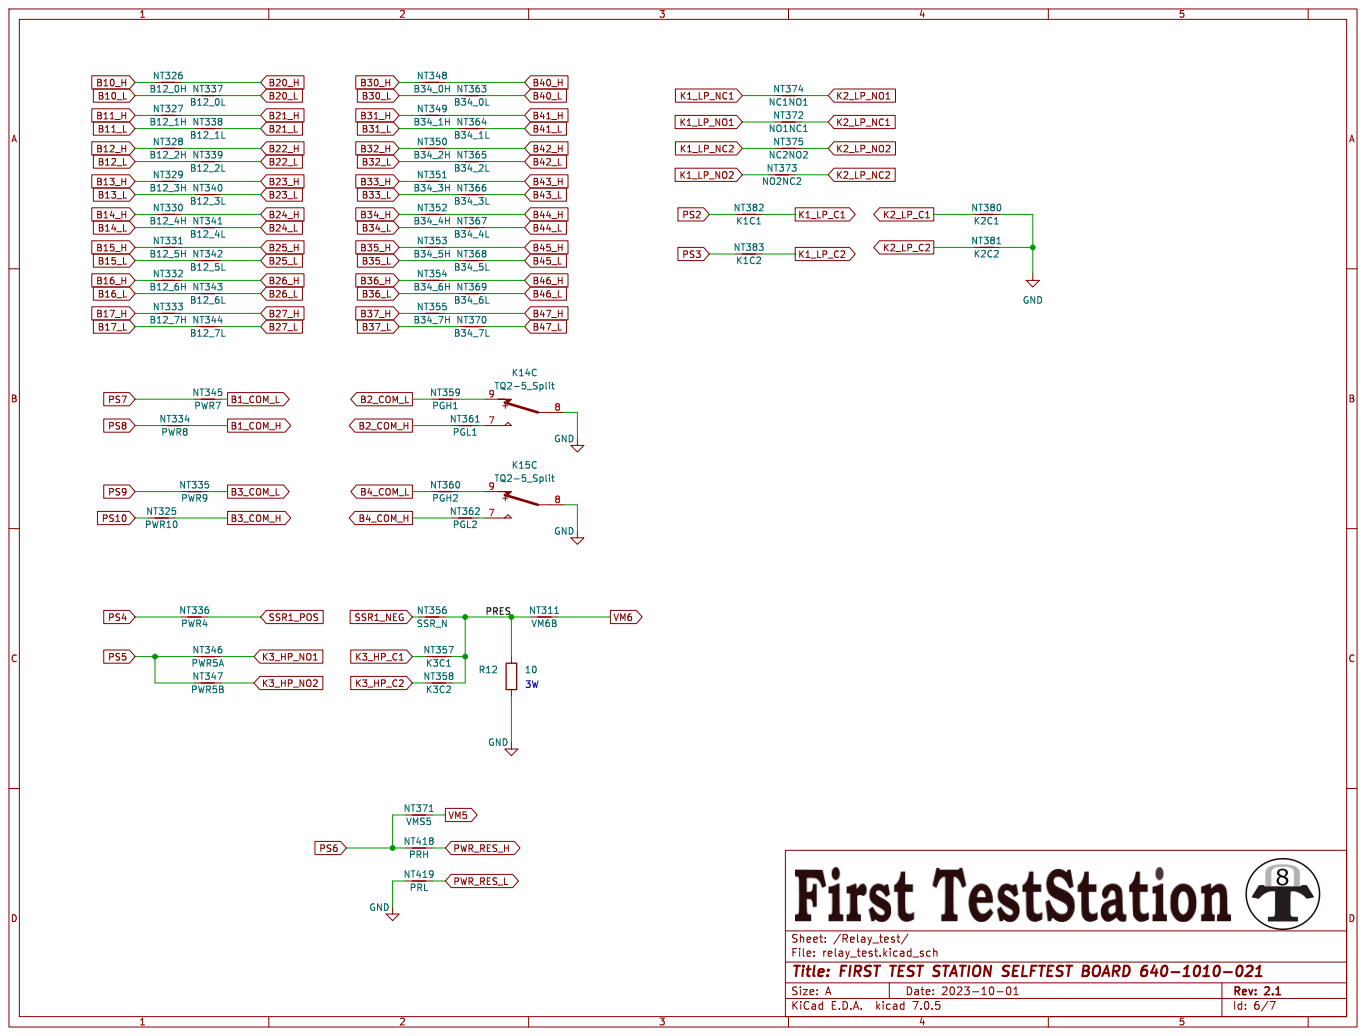
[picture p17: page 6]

Id: 6/7 Title: FIRST TEST STATION SELFTEST BOARD 640-1010-021

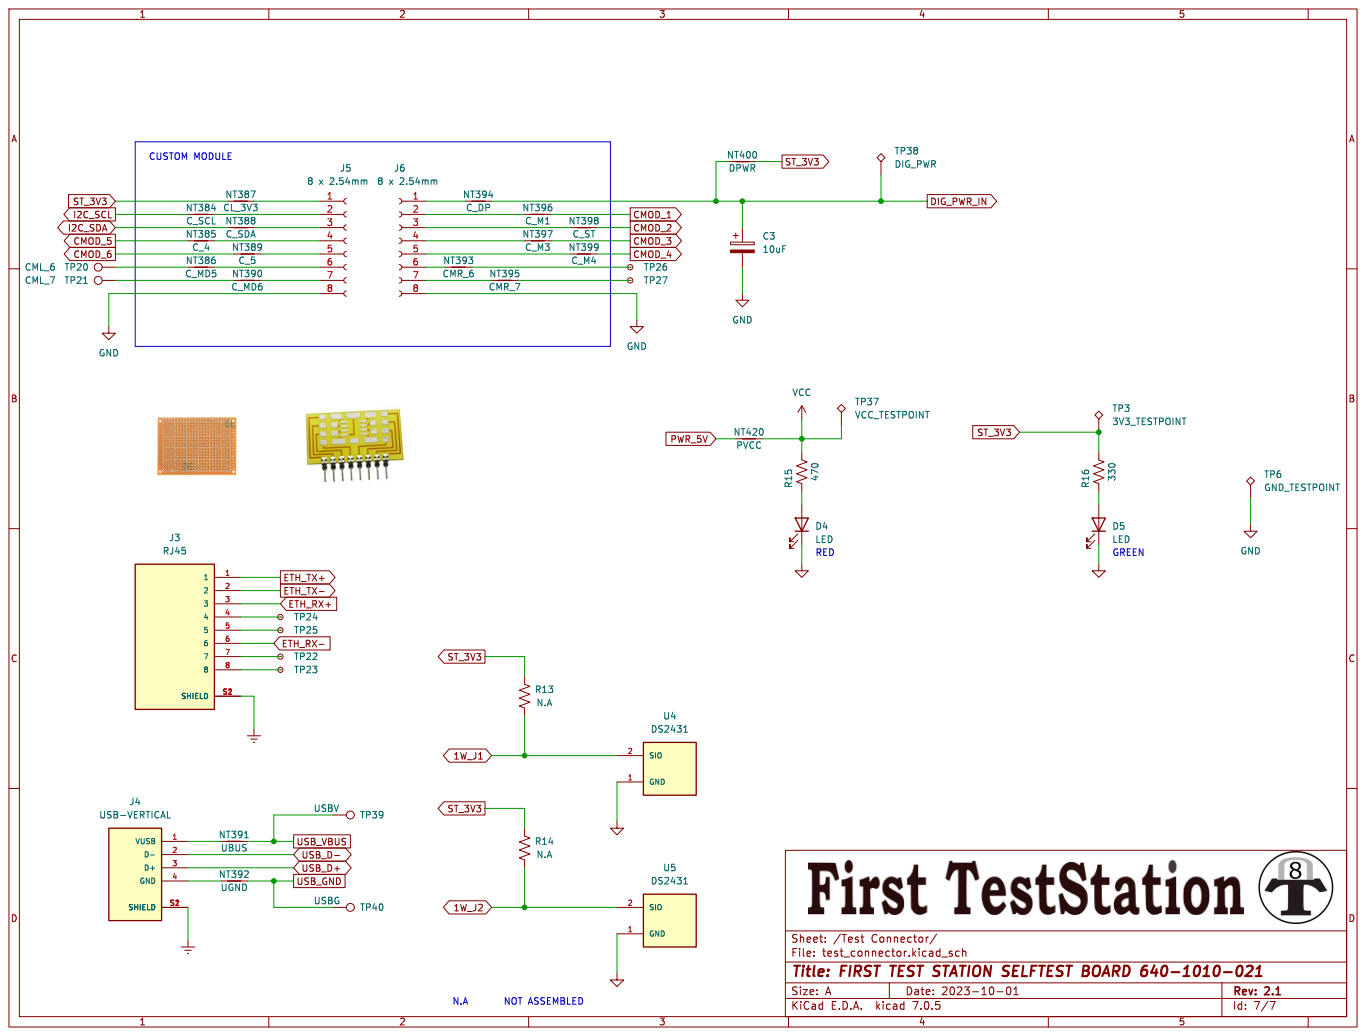
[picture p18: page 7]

File: test_connector.kicad_sch Sheet: /Test Connector/
Id: 7/7 Title: FIRST TEST STATION SELFTEST BOARD 640-1010-021

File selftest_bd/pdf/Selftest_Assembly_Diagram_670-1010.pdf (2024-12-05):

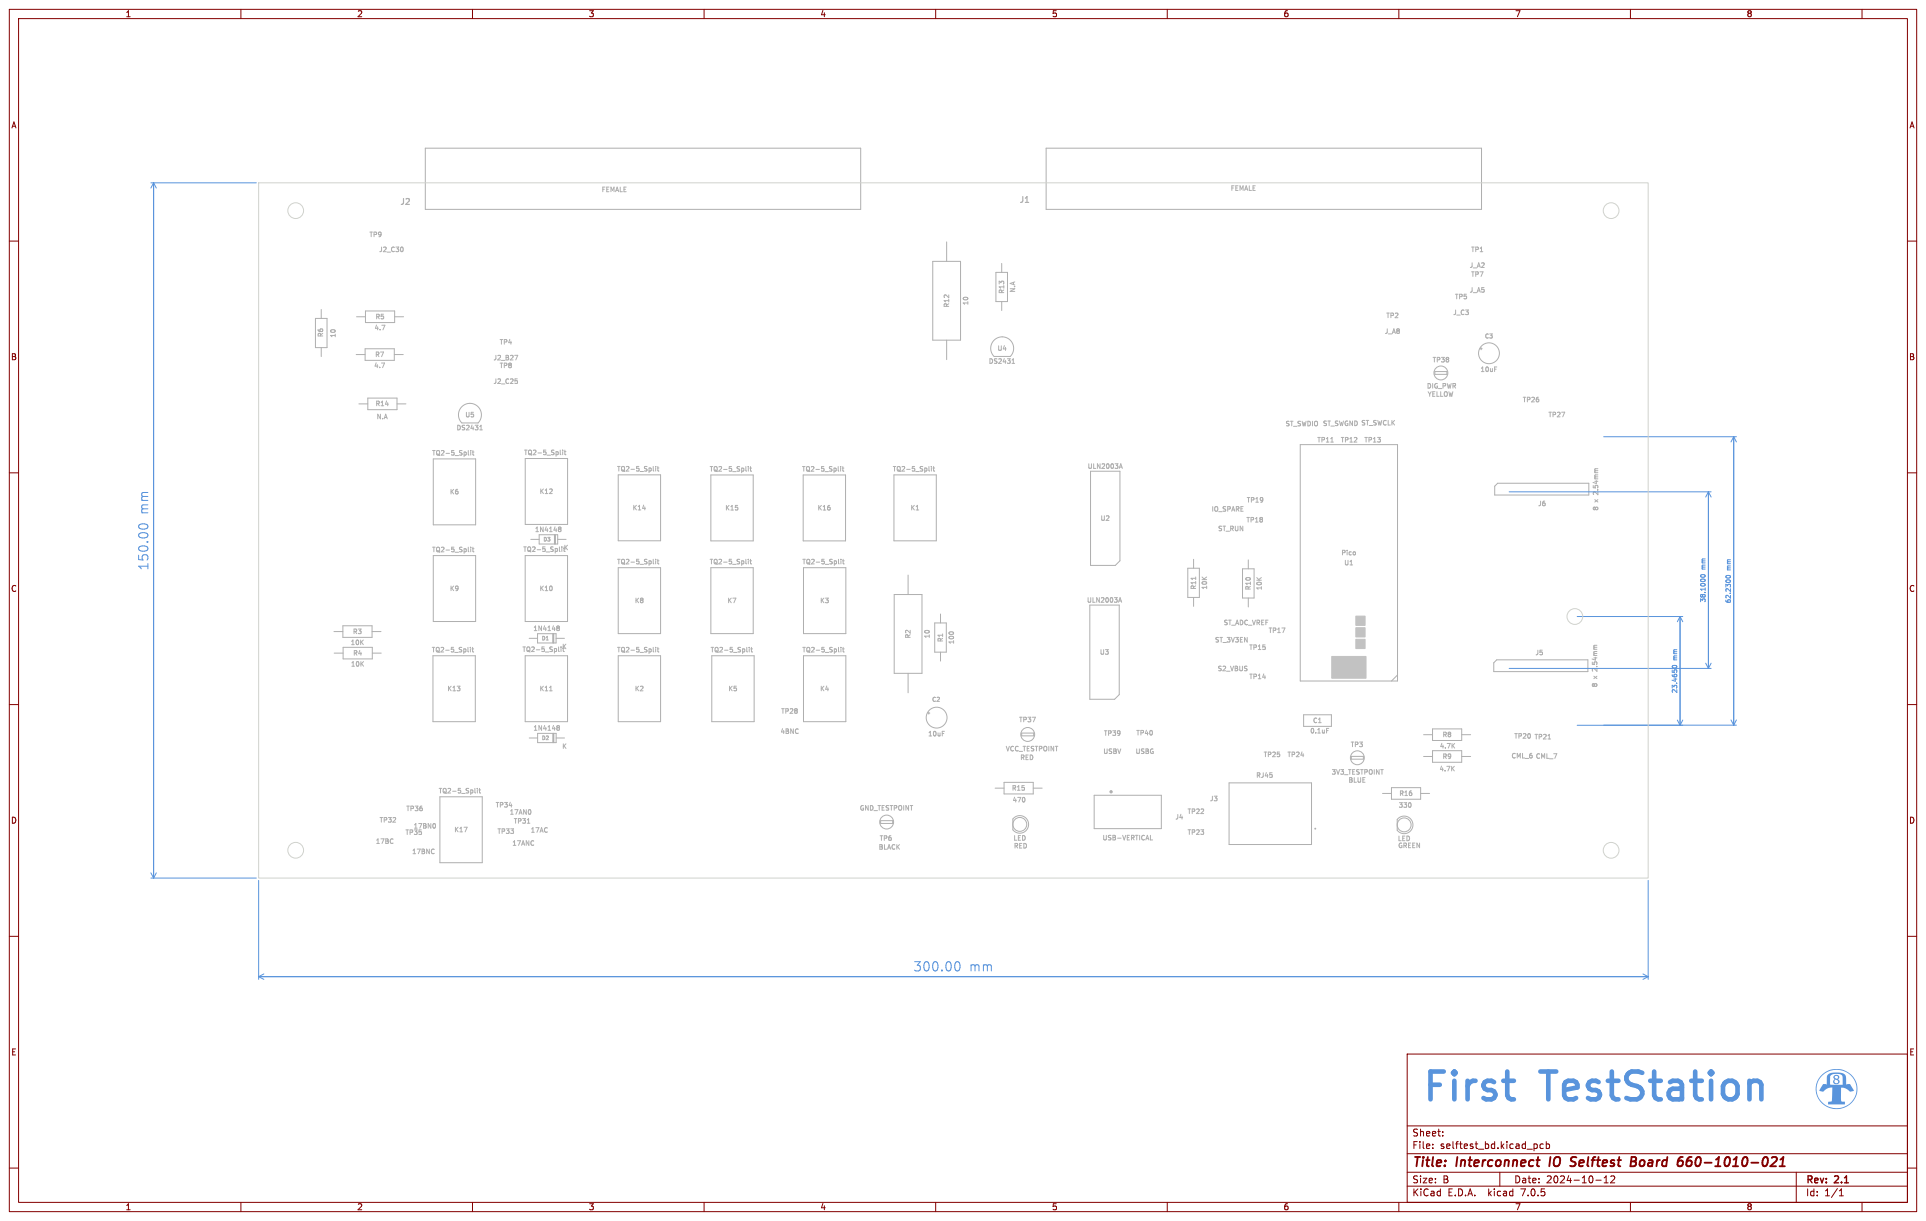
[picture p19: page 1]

8 x 2.54mmJ5 First TestStation 150.00 mm 23.4650 mm 62.2300 mm

File: selftest_bd.kicad_pcb Sheet:
Id: 1/1 Title: Interconnect IO Selftest Board 660-1010-021

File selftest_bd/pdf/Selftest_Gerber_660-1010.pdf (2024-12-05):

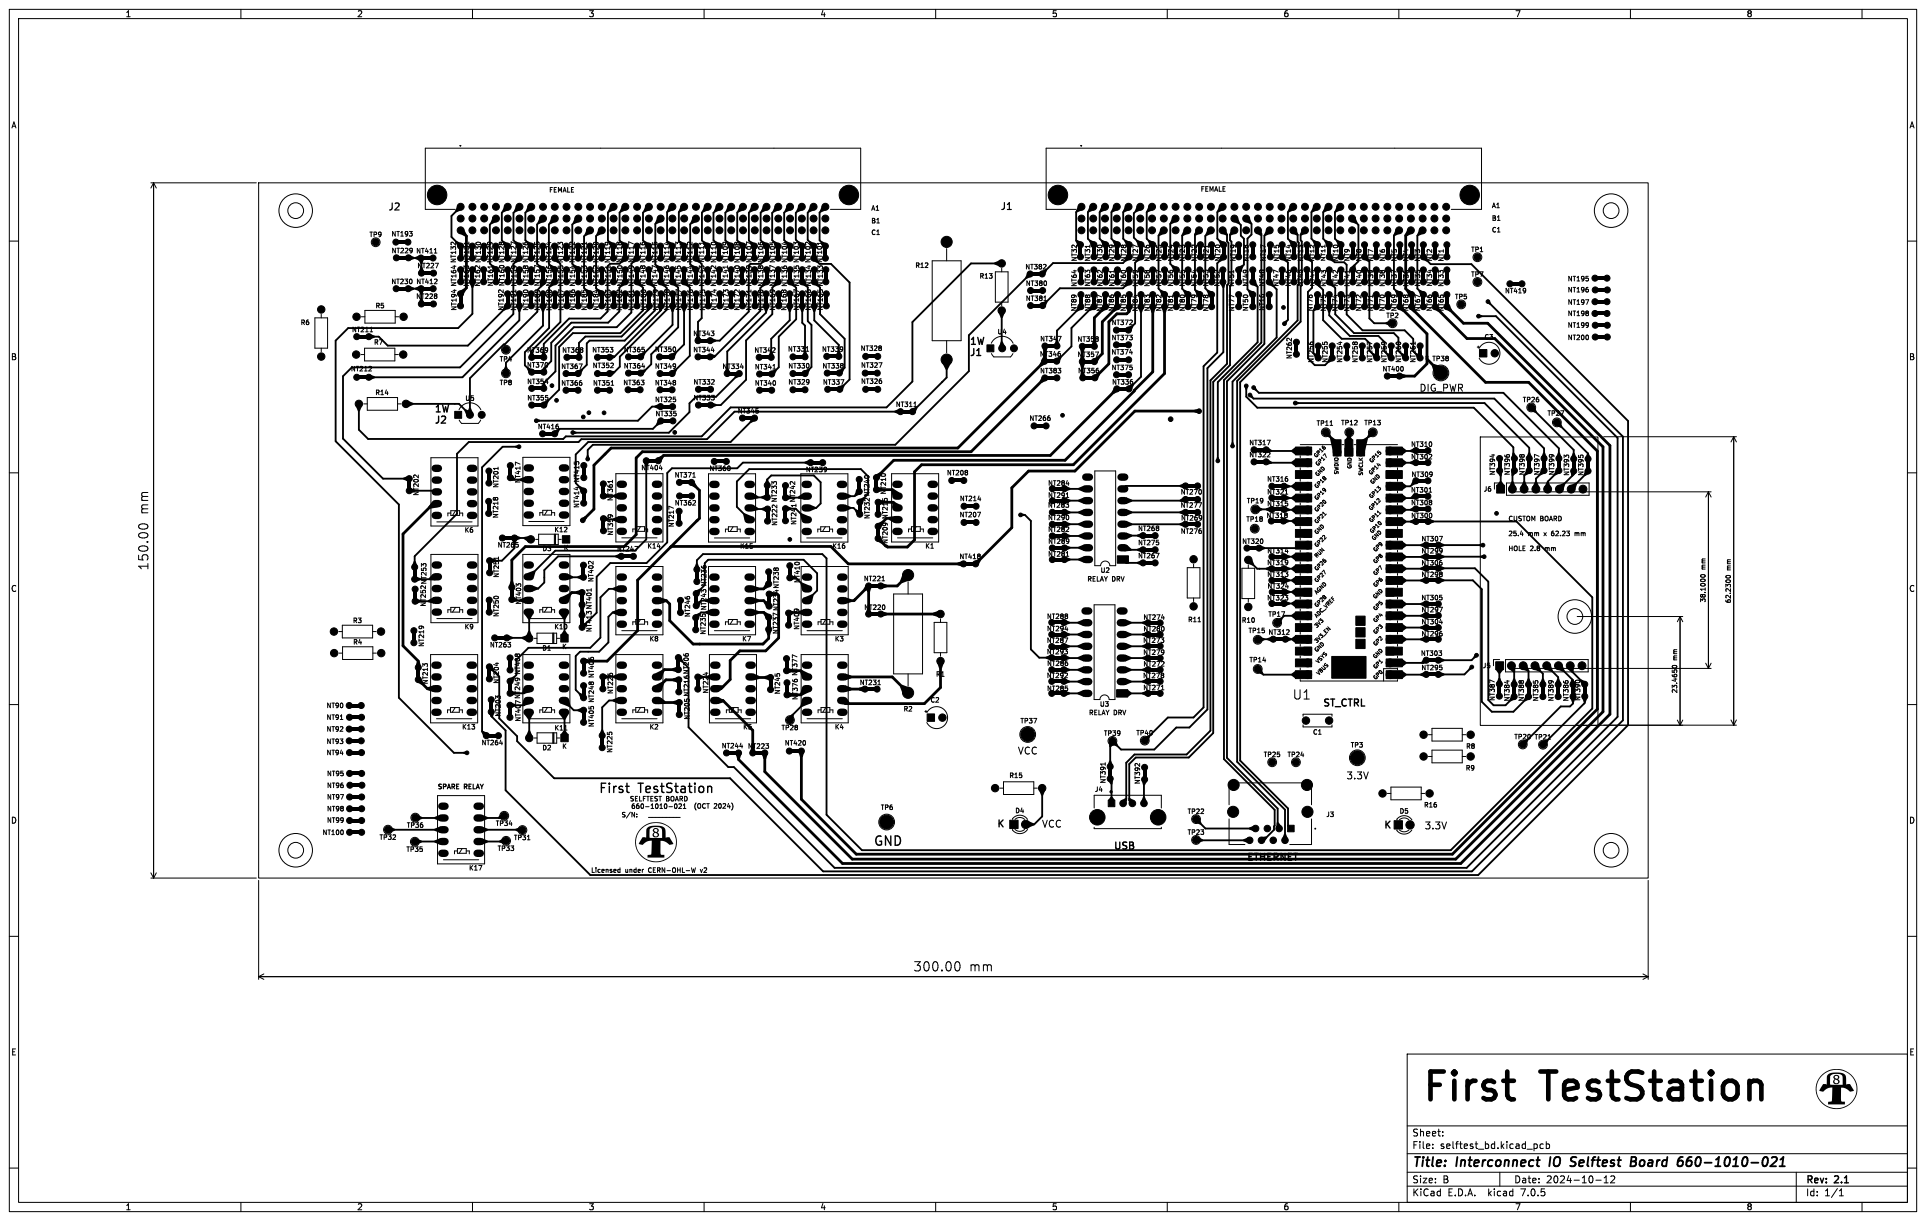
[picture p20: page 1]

Id: 1/1 Title: Interconnect IO Selftest Board 660-1010-021

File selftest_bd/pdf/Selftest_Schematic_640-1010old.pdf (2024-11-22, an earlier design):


pico File: controller.kicad_sch Test Connector File: test_connector.kicad_sch Relay_test File: relay_test.kicad_sch

File: selftest_bd.kicad_sch Sheet: /
Id: 1/7 Title: FIRST TEST STATION SELFTEST BOARD 640-1010-021

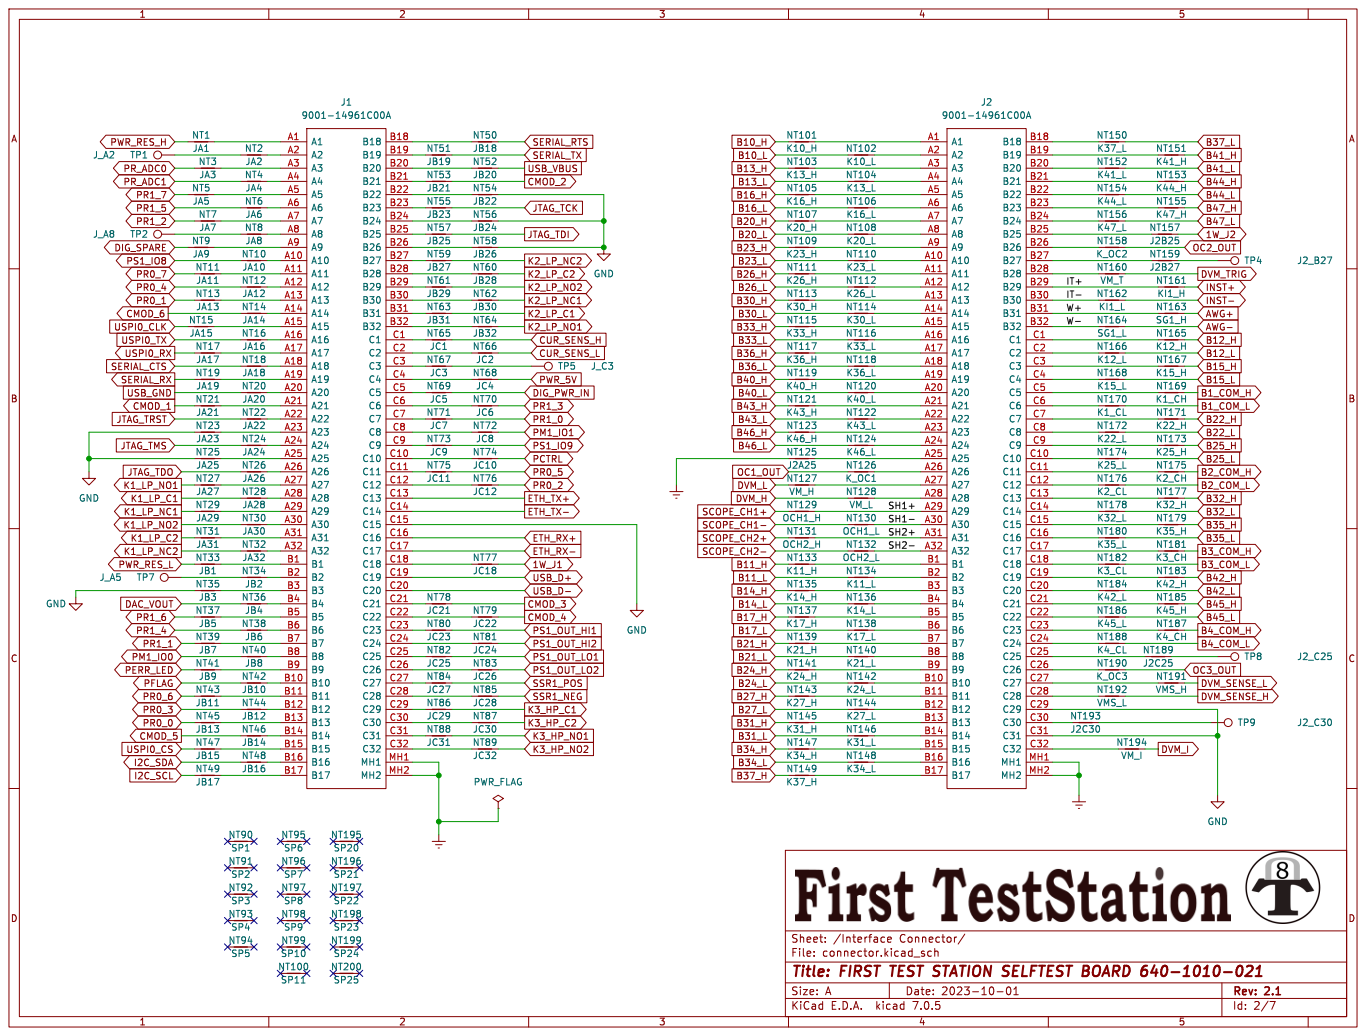
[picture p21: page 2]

Id: 2/7 Title: FIRST TEST STATION SELFTEST BOARD 640-1010-021


File: relay_driver.kicad_sch Sheet: /relay_driver/
Id: 3/7 Title: FIRST TEST STATION SELFTEST BOARD 640-1010-021


File: controller.kicad_sch Sheet: /pico/
Id: 4/7 Title: FIRST TEST STATION SELFTEST BOARD 640-1010-021


File: rswitch.kicad_sch Sheet: /relay_switch/
Id: 5/7 Title: FIRST TEST STATION SELFTEST BOARD 640-1010-021

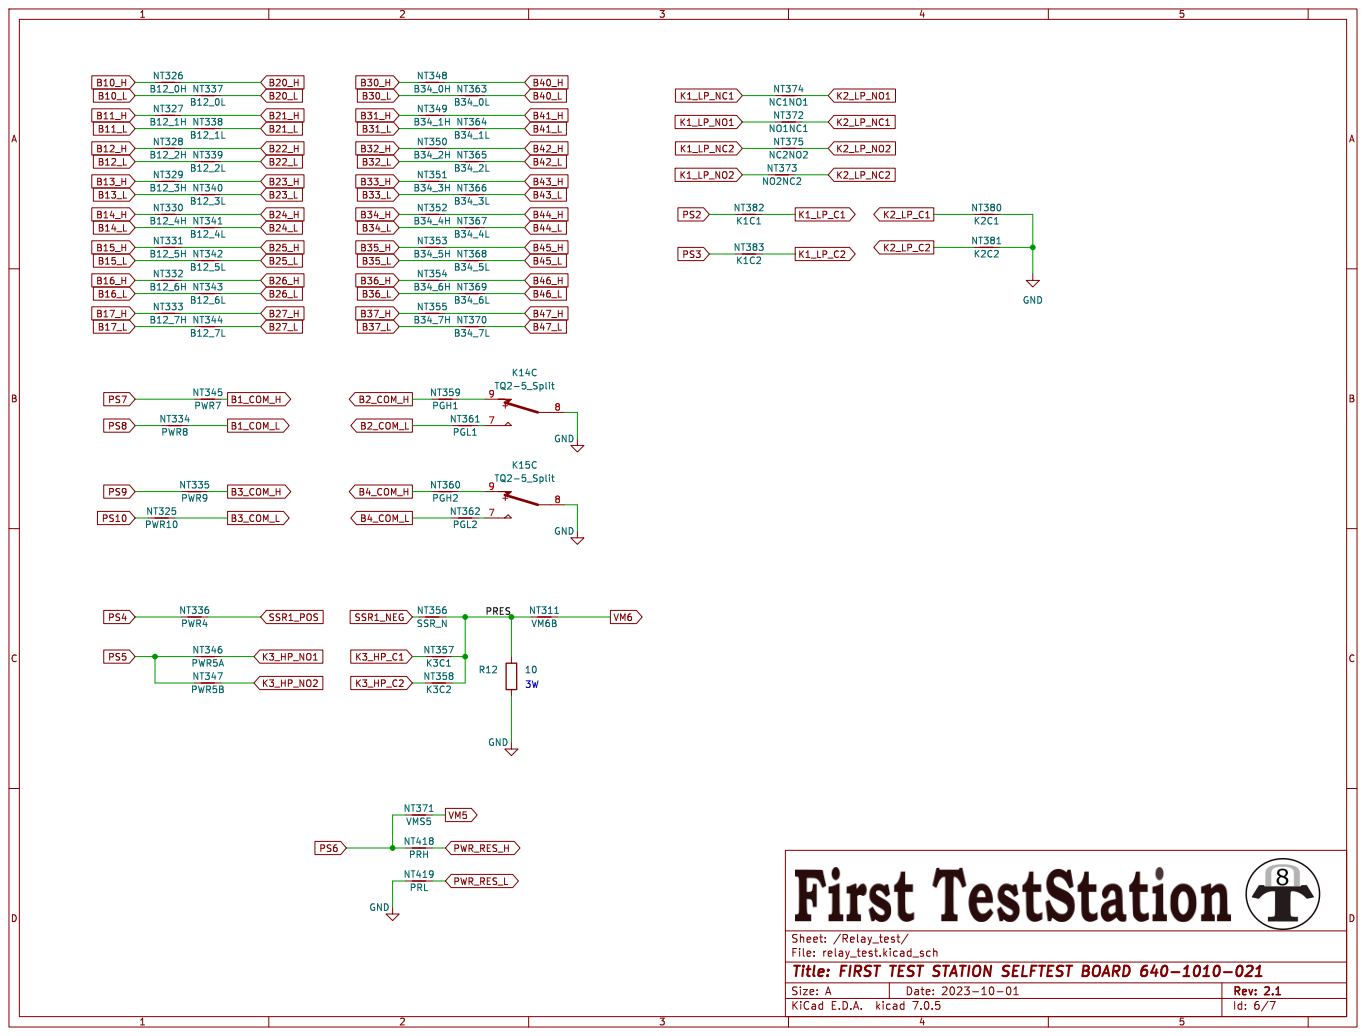
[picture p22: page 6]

Id: 6/7 Title: FIRST TEST STATION SELFTEST BOARD 640-1010-021


File: test_connector.kicad_sch Sheet: /Test Connector/
Id: 7/7 Title: FIRST TEST STATION SELFTEST BOARD 640-1010-021

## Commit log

2023-08-08 V1.0 commit
    PCB Design completed.
    [Selftest_Board.xlsx, connector.kicad_sch, controller.kicad_sch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]
2023-11-14 Commit V2.0
    Redo PCB due to incorrect position of J1 and J2
    [Selftest_Board.xlsx, connector.kicad_sch, controller.kicad_sch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]
2024-11-22 update README and small correction
    [BOM_Selftest_Board_600-1010.ods, Selftest_Board.xlsx, connector.kicad_sch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]
2024-11-22 remove not necessary files
    [selftest_bd.FCStd]
2024-12-05 Enlarge and move mounting hole. Add Socket for U4 and U5
    [BOM_Selftest_Board_600-1010.ods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]
2025-01-08 add reference to Selftest Box
    [BOM_Selftest_Board_600-1010.ods, BOM_Selftest_Board_610-1010.ods, BOM_Selftest_Box_510-1010.ods]
2025-02-06 Reverse COM_H and COM_L on relay Bank
    [connector.kicad_sch, relay_test.kicad_sch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]
